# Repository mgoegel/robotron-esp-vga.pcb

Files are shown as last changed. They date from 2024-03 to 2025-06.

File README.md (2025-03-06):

# Robotron VGA Adapter PCB

This project is based on the work of Stefan "Ordoban" Berndt.

ESP32S3 based MDA to VGA adapter

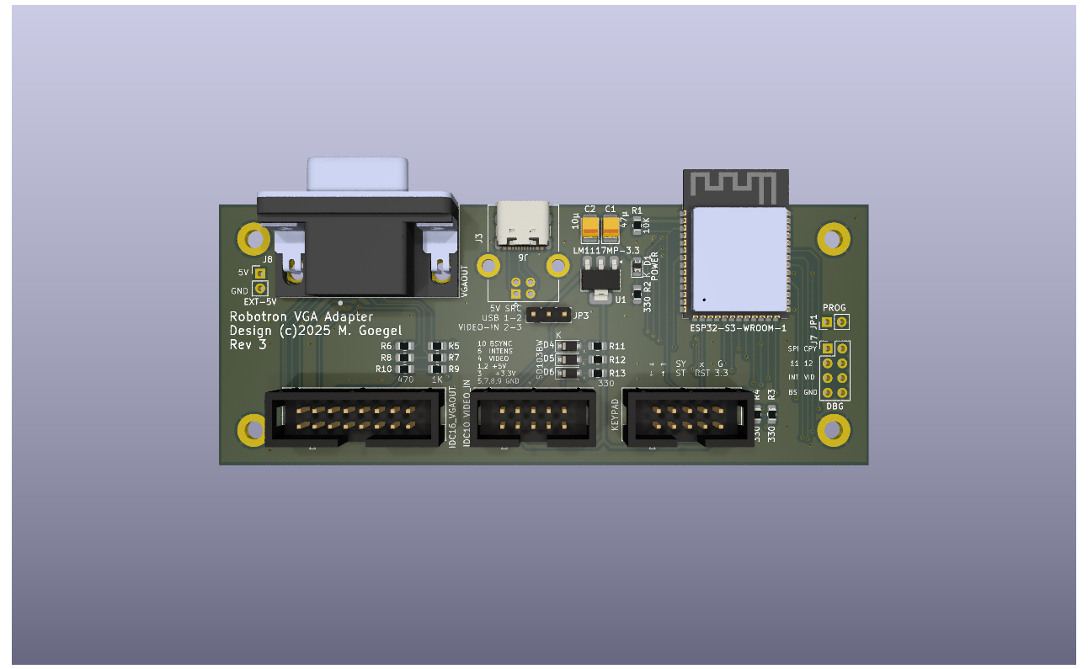
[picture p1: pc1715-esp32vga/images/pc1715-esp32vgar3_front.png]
VGA Adapter Front Adapter PCB Front
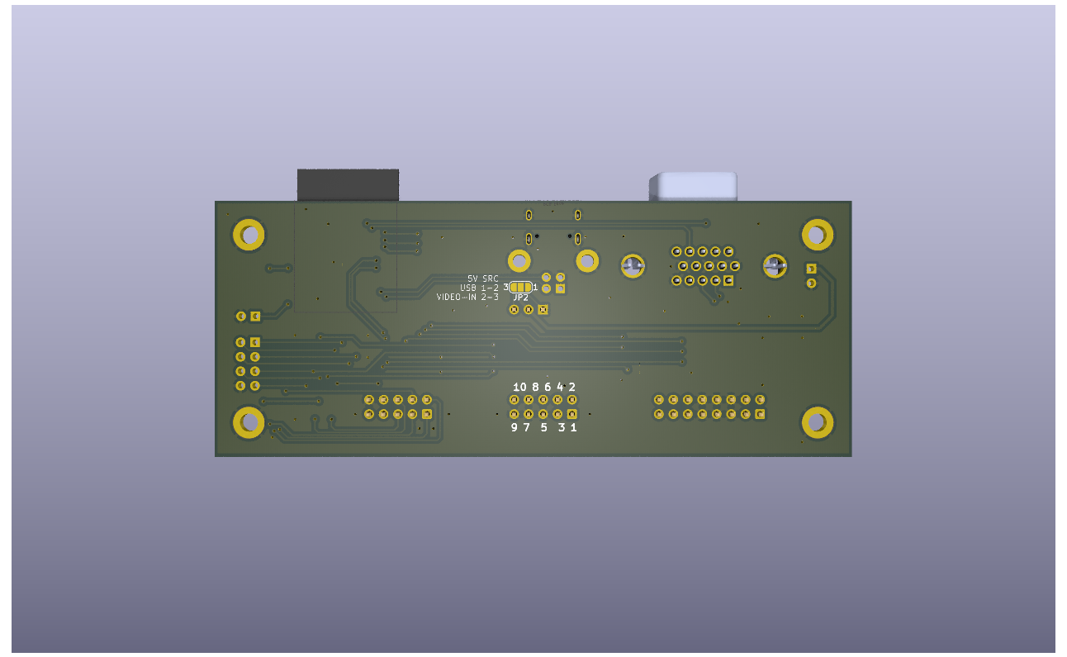
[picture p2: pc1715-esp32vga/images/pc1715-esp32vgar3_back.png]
VGA Adapter Back Adapter PCB Back
 

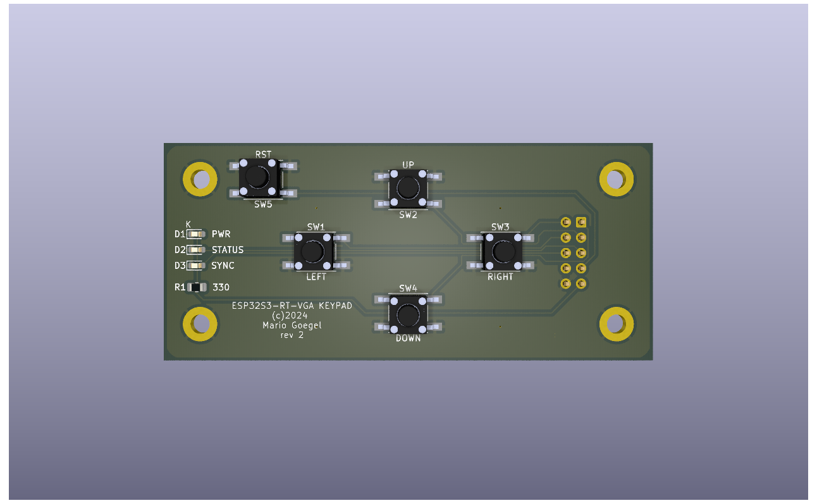
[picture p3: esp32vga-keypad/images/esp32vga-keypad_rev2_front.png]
Keypad Front
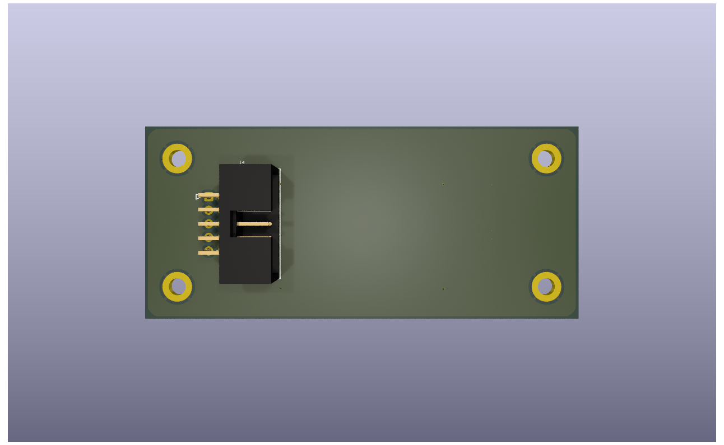
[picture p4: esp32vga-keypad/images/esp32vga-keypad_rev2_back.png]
Keypad Back
 

[Schematics](pc1715-esp32vga/schematics/pc1715-esp32vga.pdf)

Supported systems: <br>
[Connection A7100](Connections.md)
* A7100 
* A7150/CM1910 Text-only
* EC1834 MON Adapter (K7228.1, K7229.21-.24, Alpha 1 Monitor replacement)

[Connection PC1715](Connections.md)
* PC1715 
* A5120/K8924
* MC 80.30

[Connection VIDEO3/NANOS](Connections.md)
* NANOS

Published at: https://www.robotrontechnik.de/html/forum/thwb/showtopic.php?threadid=21380

The software is here: https://github.com/mgoegel/robotron-esp-vga

An (little bit outdated) order list is available at reichelt: https://www.reichelt.de/my/2181752<br>
I'll add mouser, as soon as I found out, how to publish the list... ;-)

Also you can find the BOM for both PCBs
* [Main board](pc1715-esp32vga/bom/ibom.html)
* [Keypad](esp32vga-keypad/bom/ibom.html)

### Main Board PIN Connector PINOUT

#### VGA J2 (D-SUB 15HD) / J5 (IDC16_VGA)

| D_SUB 15 HD | Signal | Pin | Pin | Signal | D_SUB 15 HD |
| --- | --- | --- | --- | --- | --- |
| 1 | RED | 1 | 2 | GREEN  | 2 |
| 3 | BLUE | 3 | 4 | NC | |
| 6 | GND | 5 | 6 | GND | 5 |
| 7 | GND | 7 | 8 | GND | 10 |
| 8 | GND | 9 | 10  | GND | NC |
| | NC | 11  | 12  | NC | |
| 13 | HSYNC  | 13  | 14  | VSYNC  | 14 |
| | NC | 15  | 16  | NC | |

#### VIDEO IN J1

| Signal | Pin | Pin | Signal |
| --- | --- | --- | --- |
| 5V IN | 1 | 2 | 5V IN  |
| 3.3V IN/OUT | 3 | 4 | VIDEO  |
| GND | 5 | 6 | INTENS |
| GND | 7 | 8 | GND |
| GND | 9 | 10  | BSYNC  |

#### KEYPAD J4

| Signal  | Pin | Pin | Signal  |
| --- | --- | --- | --- |
| K_DOWN  | 1 | 2 | K_RIGHT |
| K_UP | 3 | 4 | K_LEFT  |
| L_STAT  | 5 | 6 | L_SYNC  |
| RST | 7 | 8 | NC |
| 3.3V | 9 | 10  | GND |

#### DEBUG J7 2x04

| Signal | Pin | Pin | Signal |
| --- | --- | --- | --- |
| TP-SPI | 1 | 2 | TP-CPY |
| TP-11  | 3 | 4 | TP-12  |
| INTENS | 5 | 6 | VIDEO  |
| BSYNC  | 7 | 8 | GND |

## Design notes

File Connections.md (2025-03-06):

         ESP32S3VGA                                      PC1715            
          VIDEO-IN                                                         
                                                                           
                                                          A  B             
          ┌──────┐                                     ┌────────┐          
          │      │                                     │        │          
    BSYNC │ 0    ├───────────────────────────┐  ┌──────┤  1     │  INTENS  
       GND│    9 │                           │  │      │        │          
    GND   │ 8    ├───────────────────────────┼──┼──────┤     2  │  GND     
       GND│    7 │                      ┌────┼──┘      │        │          
    INTENS│ 6    ├──────────────────────┘    └─────────┤  3     │  BSYN    
       GND│    5 │                                     │        │          
    VIDEO │ 4    ├──────────────────────┐              │     4  │  SHIELD  
       3V3│    3 │                      │              │        │          
    5V    │ 2    │                      └──────────────┤  5     │  VIDEO   
        5V│    1 │                                     │        │          
          │      │<                                    └────────┘          
          └──────┘                                                         

         ESP32S3VGA                                     EC1834MON          
          VIDEO-IN                                        ALPHA1           
                                                                           
          ┌──────┐                                                         
          │      │                                     ┌─────────┐         
    BSYNC │ 0    ├────────┐                            │         │         
       GND│    9 │        │                            │     5   │         
    GND   │ 8    ├────┐   │   ┌────────────────────────┤  6      │  INTENS 
       GND│    7 │    │   │   │                        │     4   │       NC
    INTENS│ 6    ├────┼───┼───┘  ┌─────────────────────┤  7      │  VIDEO  
       GND│    5 │    │   │      │                     │     3   │       NC
    VIDEO │ 4    ├────┼───┼──────┘                     │  8      │  NC     
       3V3│    3 │    └───┼────────────────────────────┤     2   │      GND
    5V    │ 2    │        └────────────────────────────┤  9      │  BSYN   
        5V│    1 │                                     │     1   │      GND
          │      │<                                    │         │         
          └──────┘                                     └─────────┘         

        ESP32S3VGA                                       VIDEO3          
          VIDEO-IN                                        NANOS          
                                                                         
                                                          A  B           
          ┌──────┐                                     ┌────────┐        
          │      │                                     │        │        
    BSYNC │ 0    ├───────────────────────────┐         │  1     │  (BAS) 
       GND│    9 │                           │         │        │        
    GND   │ 8    ├───────────────────────────┼─────────┤     2  │  GND   
       GND│    7 │                           │         │        │        
    INTENS│ 6    │                           └─────────┤  3     │  BSYN  
       GND│    5 │                                     │        │        
    VIDEO │ 4    ├──────────────────────┐              │     4  │  SHIELD
       3V3│    3 │                      │              │        │        
    5V    │ 2    │                      └──────────────┤  5     │  VIDEO 
        5V│    1 │                                     │        │        
          │      │<                                    └────────┘        
          └──────┘

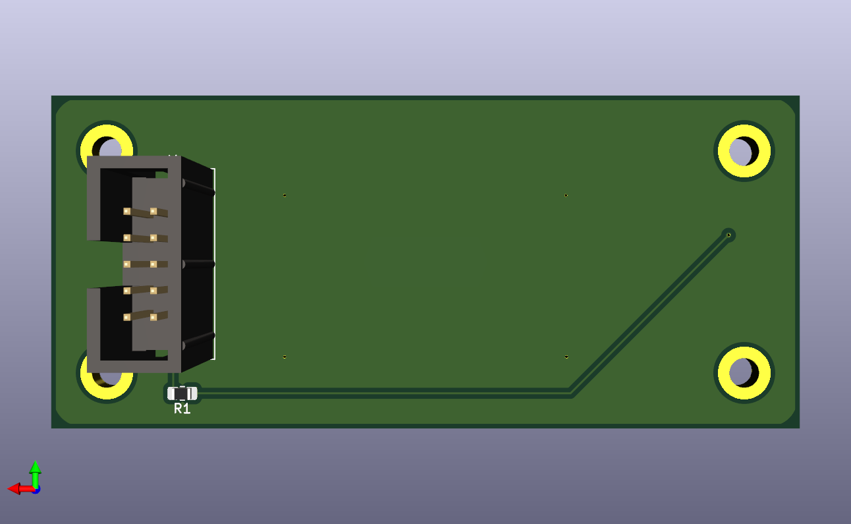
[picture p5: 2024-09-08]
esp32vga-keypad/images/esp32vga-keypad_back.png

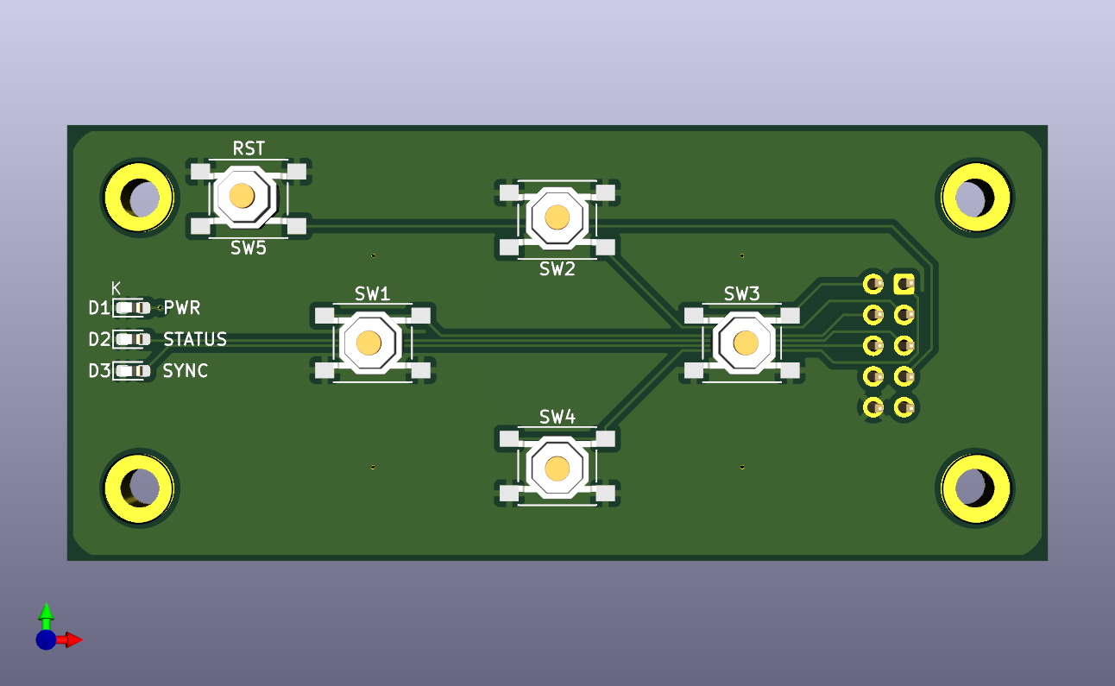
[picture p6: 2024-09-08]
esp32vga-keypad/images/esp32vga-keypad_front.png

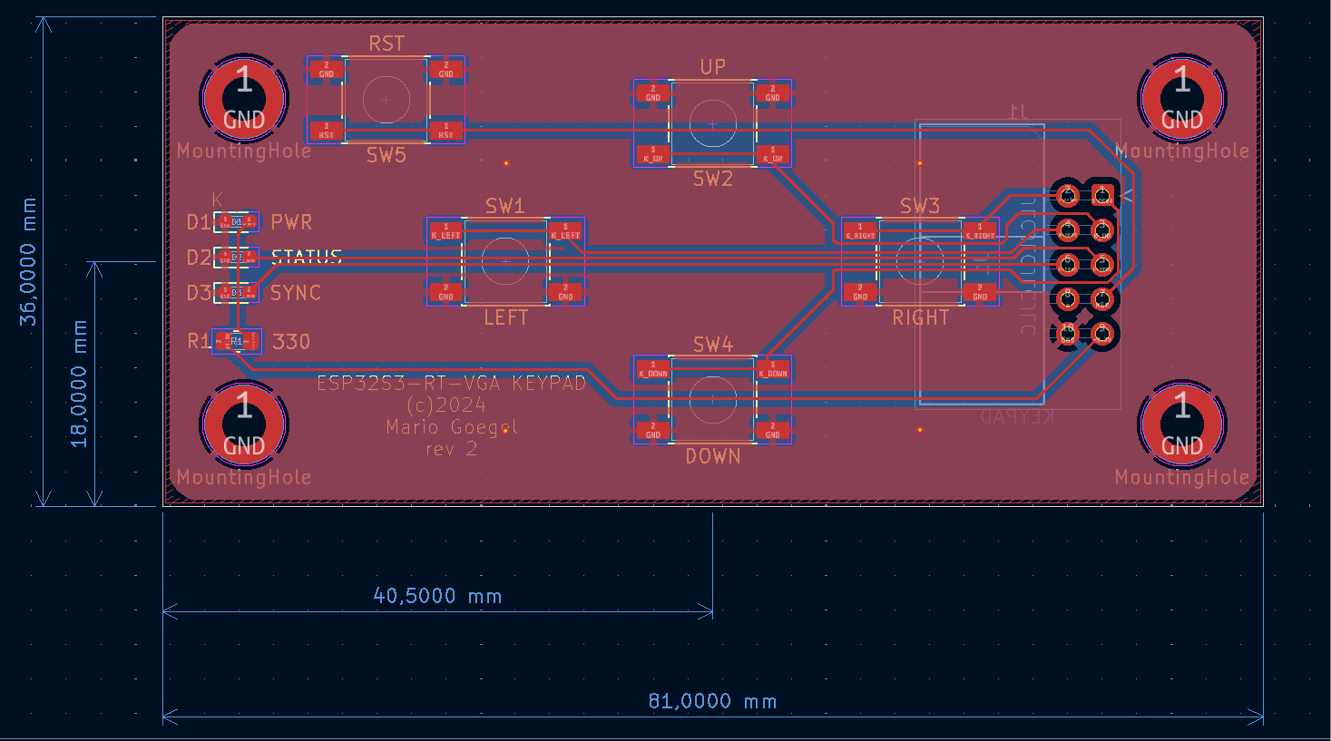
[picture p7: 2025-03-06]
esp32vga-keypad/images/esp32vga-keypad_rev2_pcb.png

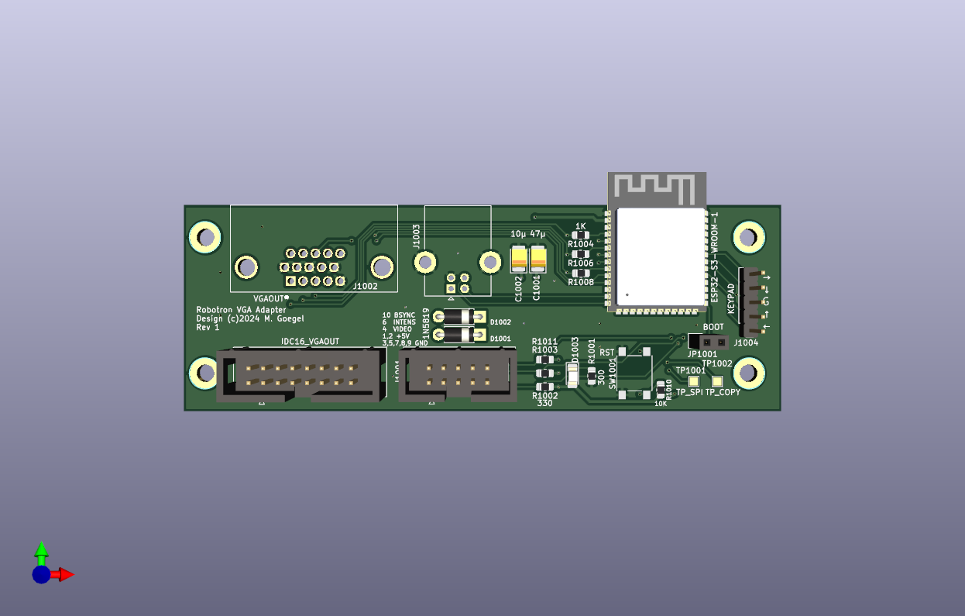
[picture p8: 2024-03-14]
pc1715-esp32vga/images/pc1715-esp32vga_front.png

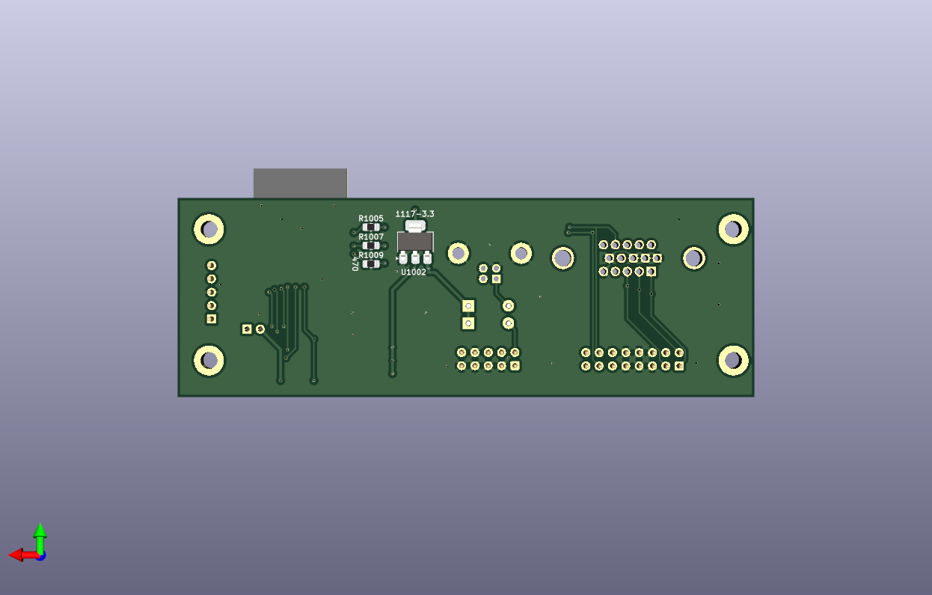
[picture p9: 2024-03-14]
pc1715-esp32vga/images/pc1715-esp32vga_back.png

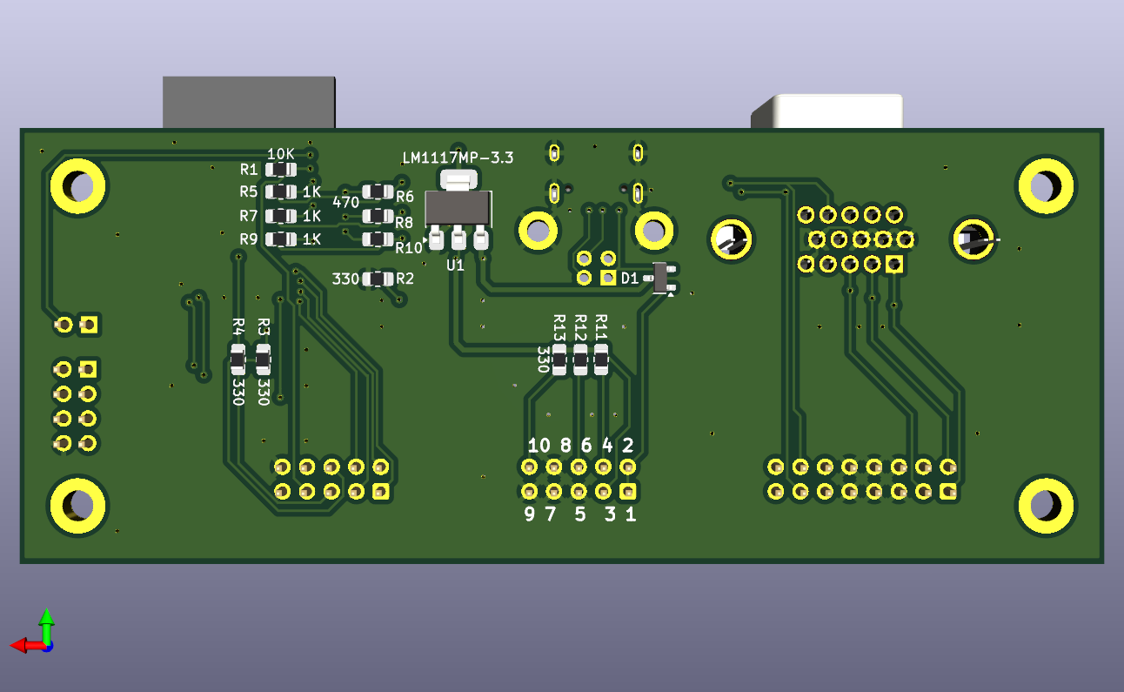
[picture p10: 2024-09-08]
pc1715-esp32vga/images/pc1715-esp32vgar2_back.png

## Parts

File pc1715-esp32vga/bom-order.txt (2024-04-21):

Reference	Value	Footprint	Qty	mouser	reichelt
C1001	47µ	Capacitor_Tantalum_SMD:CP_EIA-3528-21_Kemet-B_Pad1.50x2.35mm_HandSolder	1	581-TAJB476M010SNJ	TPS 3225 47/10
C1002	10µ	Capacitor_Tantalum_SMD:CP_EIA-3528-21_Kemet-B_Pad1.50x2.35mm_HandSolder	1	80-T491B106M020	TAJ 3528 10/20
D1001,D1002	1N5819	Diode_THT:D_DO-41_SOD81_P7.62mm_Horizontal	2	637-1N5819	1N 5819
D1003	LED	LED_SMD:LED_1206_3216Metric_Pad1.42x1.75mm_HandSolder	1	645-597-5411-407NF	SMD-LED 0805 GE
J1001	IDC10_VIDEO_IN	Connector_IDC:IDC-Header_2x05_P2.54mm_Vertical	1	710-61201021621	WSL 10G
J1002	VGAOUT	00esp32vga-footprints:TE_1-1734530-1	1	HD 15FW	571-2311763-1
J1003	USB_B	Connector_USB:USB_B_Lumberg_2411_02_Horizontal	1	USB BW	179-UJ2-B-HR-G-TH
J1004	KEYPAD	Connector_PinHeader_2.54mm:PinHeader_1x05_P2.54mm_Vertical	1		
J1005	IDC16_VGAOUT	Connector_IDC:IDC-Header_2x08_P2.54mm_Vertical	1	710-61201621621	WSL 16G
JP1001	BOOT	Connector_PinSocket_2.54mm:PinSocket_1x02_P2.54mm_Vertical	1		
R1001	300	Resistor_SMD:R_0805_2012Metric_Pad1.20x1.40mm_HandSolder	1		
R1002,R1003,R1011	330	Resistor_SMD:R_0805_2012Metric_Pad1.20x1.40mm_HandSolder	3		
R1004,R1006,R1008	1K	Resistor_SMD:R_0805_2012Metric_Pad1.20x1.40mm_HandSolder	3		
R1005,R1007,R1009	470	Resistor_SMD:R_0805_2012Metric_Pad1.20x1.40mm_HandSolder	3		
R1010	10K	Resistor_SMD:R_0805_2012Metric_Pad1.20x1.40mm_HandSolder	1		
SW1001	RST	Button_Switch_SMD:SW_Push_1P1T_NO_6x6mm_H9.5mm	1	653-B3FS-1002P	TASTER 9313
U1001	ESP32-S3-WROOM-1	PCM_Espressif:ESP32-S3-WROOM-1	1	356-ESP32S3WRM1UN8R8	ESP32S3WRM1N8R8
U1002	LM1117MP-3.3	Package_TO_SOT_SMD:SOT-223-3_TabPin2	1	926-LM1117MPX3.3NOPB	LM 1117 MPX-3.3

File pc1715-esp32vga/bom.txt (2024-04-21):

Reference	Value	Footprint	Qty	DNP
C1001	47µ	Capacitor_Tantalum_SMD:CP_EIA-3528-21_Kemet-B_Pad1.50x2.35mm_HandSolder	1	
C1002	10µ	Capacitor_Tantalum_SMD:CP_EIA-3528-21_Kemet-B_Pad1.50x2.35mm_HandSolder	1	
D1001,D1002	1N5819	Diode_THT:D_DO-41_SOD81_P7.62mm_Horizontal	2	
D1003	LED	LED_SMD:LED_1206_3216Metric_Pad1.42x1.75mm_HandSolder	1	
H1001,H1002,H1003,H1004	MountingHole	MountingHole:MountingHole_3.2mm_M3_ISO7380_Pad	4	
J1001	IDC10_VIDEO_IN	Connector_IDC:IDC-Header_2x05_P2.54mm_Vertical	1	
J1002	VGAOUT	00esp32vga-footprints:TE_1-1734530-1	1	
J1003	USB_B	Connector_USB:USB_B_Lumberg_2411_02_Horizontal	1	
J1004	KEYPAD	Connector_PinHeader_2.54mm:PinHeader_1x05_P2.54mm_Vertical	1	
J1005	IDC16_VGAOUT	Connector_IDC:IDC-Header_2x08_P2.54mm_Vertical	1	
JP1001	BOOT	Connector_PinSocket_2.54mm:PinSocket_1x02_P2.54mm_Vertical	1	
R1001	300	Resistor_SMD:R_0805_2012Metric_Pad1.20x1.40mm_HandSolder	1	
R1002,R1003,R1011	330	Resistor_SMD:R_0805_2012Metric_Pad1.20x1.40mm_HandSolder	3	
R1004,R1006,R1008	1K	Resistor_SMD:R_0805_2012Metric_Pad1.20x1.40mm_HandSolder	3	
R1005,R1007,R1009	470	Resistor_SMD:R_0805_2012Metric_Pad1.20x1.40mm_HandSolder	3	
R1010	10K	Resistor_SMD:R_0805_2012Metric_Pad1.20x1.40mm_HandSolder	1	
SW1001	RST	Button_Switch_SMD:SW_Push_1P1T_NO_6x6mm_H9.5mm	1	
TP1001	TP_SPI	TestPoint:TestPoint_Pad_1.5x1.5mm	1	
TP1002	TP_COPY	TestPoint:TestPoint_Pad_1.5x1.5mm	1	
U1001	ESP32-S3-WROOM-1	PCM_Espressif:ESP32-S3-WROOM-1	1	
U1002	LM1117MP-3.3	Package_TO_SOT_SMD:SOT-223-3_TabPin2	1

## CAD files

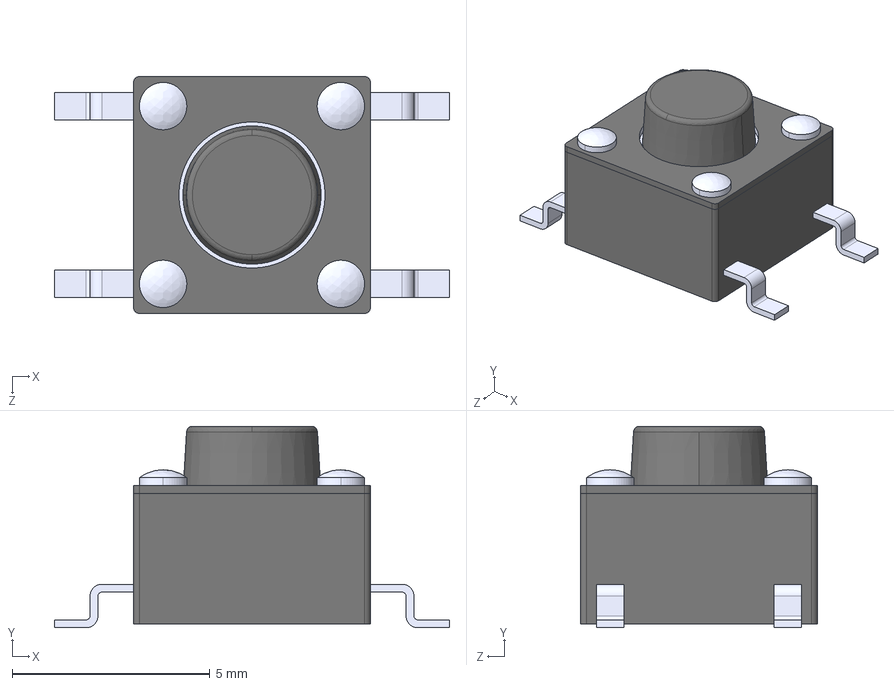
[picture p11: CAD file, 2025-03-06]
esp32vga-keypad/3d/TS04-66-50-BK-160-SMT.stp
10.0 x 5.10 x 6.00 mm

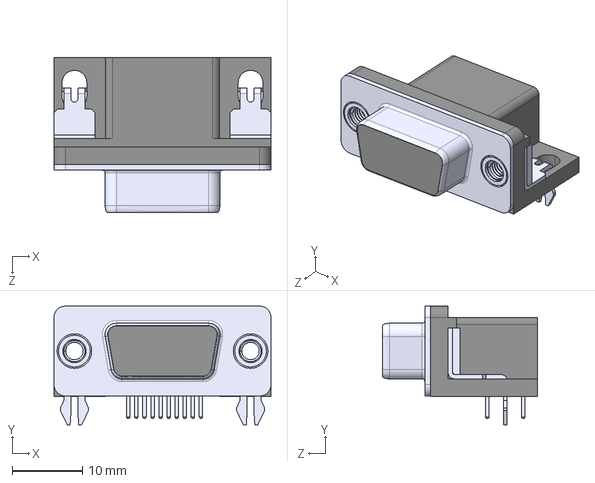
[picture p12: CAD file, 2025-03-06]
pc1715-esp32vga/3d/1-1734530-1.--3DModel-STEP-56544.STEP
30.8 x 16.9 x 22.0 mm

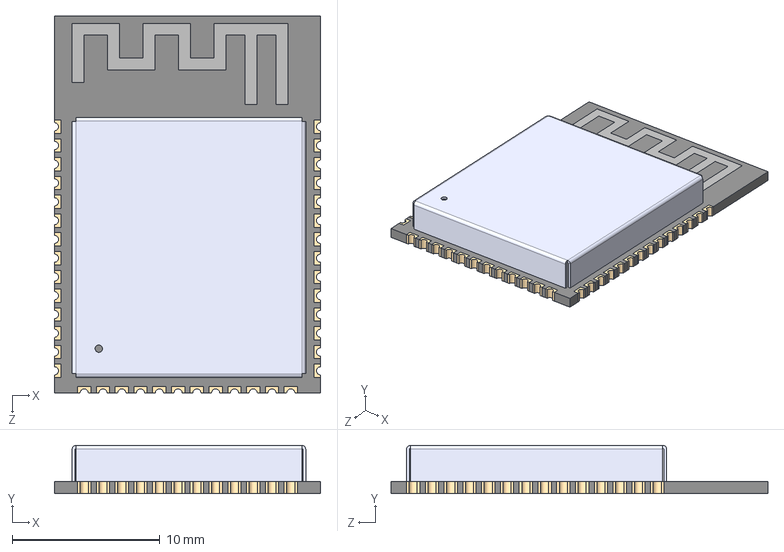
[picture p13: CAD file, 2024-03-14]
pc1715-esp32vga/3d/ESP32S3WROOM1N16R2.STEP
18.0 x 3.25 x 25.5 mm

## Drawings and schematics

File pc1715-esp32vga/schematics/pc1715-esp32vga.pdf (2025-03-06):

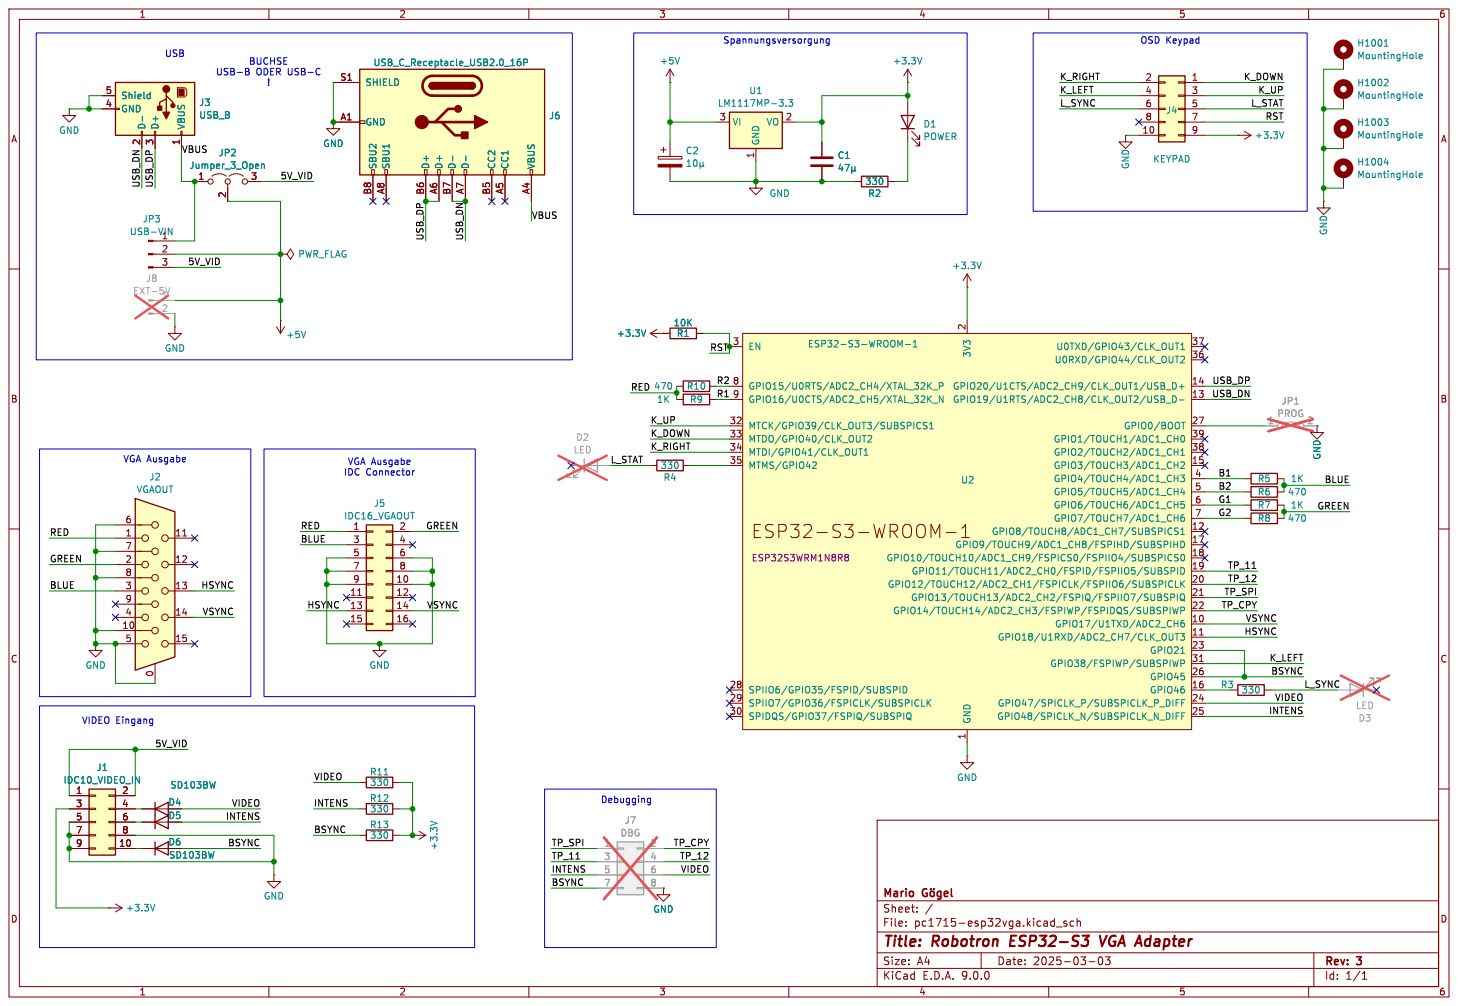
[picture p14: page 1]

1 U0TXD/GPIO43/CLK_OUT1 37 U0RXD/GPIO44/CLK_OUT2 36 GPIO20/U1CTS/ADC2_CH9/CLK_OUT1/USB_D+ 14 GPIO19/U1RTS/ADC2_CH8/CLK_OUT2/USB_D- 13 GPIO0/BOOT 27 GPIO1/TOUCH1/ADC1_CH0 39 GPIO2/TOUCH2/ADC1_CH1 38 GPIO3/TOUCH3/ADC1_CH2 15 GPIO4/TOUCH4/ADC1_CH3 4 GPIO5/TOUCH5/ADC1_CH4 5 GPIO6/TOUCH6/ADC1_CH5 6 GPIO7/TOUCH7/ADC1_CH6 7 GPIO8/TOUCH8/ADC1_CH7/SUBSPICS1 12 GPIO9/TOUCH9/ADC1_CH8/FSPIHD/SUBSPIHD 17 GPIO10/TOUCH10/ADC1_CH9/FSPICS0/FSPIIO4/SUBSPICS0 18 GPIO11/TOUCH11/ADC2_CH0/FSPID/FSPIIO5/SUBSPID 19 GPIO12/TOUCH12/ADC2_CH1/FSPICLK/FSPIIO6/SUBSPICLK 20 GPIO13/TOUCH13/ADC2_CH2/FSPIQ/FSPIIO7/SUBSPIQ 21 GPIO14/TOUCH14/ADC2_CH3/FSPIWP/FSPIDQS/SUBSPIWP 22 GPIO17/U1TXD/ADC2_CH6 10 GPIO18/U1RXD/ADC2_CH7/CLK_OUT3 11 GPIO21 23 GPIO38/FSPIWP/SUBSPIWP 31 GPIO45 26 GPIO46 16 GPIO47/SPICLK_P/SUBSPICLK_P_DIFF 24 GPIO48/SPICLK_N/SUBSPICLK_N_DIFF 25 U2 ESP32-S3-WROOM-1 ESP32S3WRM1N8R8

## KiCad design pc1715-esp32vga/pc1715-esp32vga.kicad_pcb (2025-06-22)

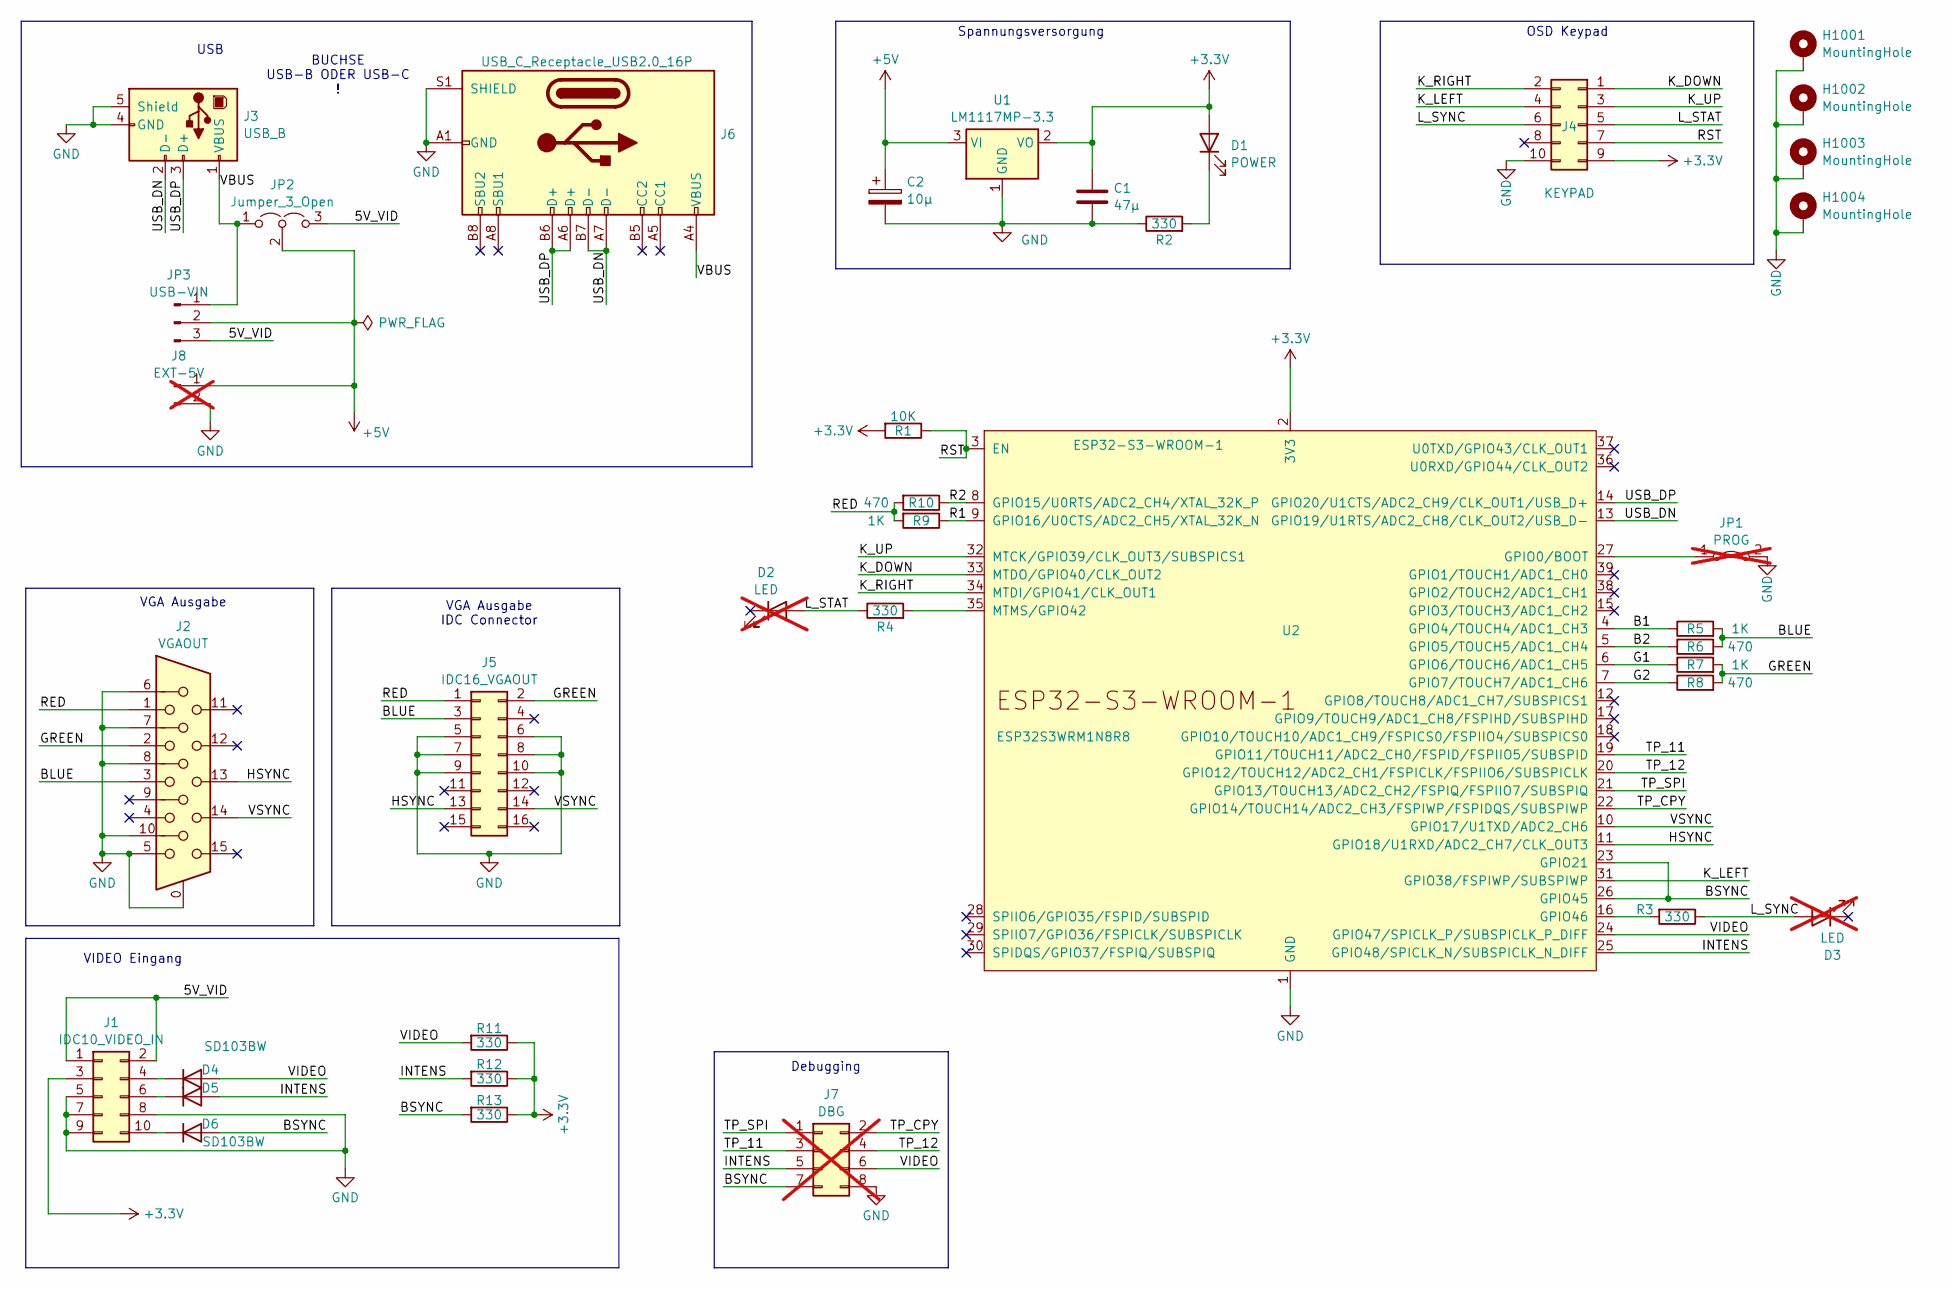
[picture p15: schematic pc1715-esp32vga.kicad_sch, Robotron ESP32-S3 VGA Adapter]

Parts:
C1: 47µ; CP_EIA-3528-21_Kemet-B_Pad1.50x2.35mm_HandSolder
C2: 10µ; CP_EIA-3528-21_Kemet-B_Pad1.50x2.35mm_HandSolder
D1: POWER; D_0805_2012Metric_Pad1.15x1.40mm_HandSolder
D2, D3: LED; not fitted
D4, D5, D6: SD103BW; D_SOD-123
H1001, H1002, H1003, H1004: MountingHole; MountingHole_3.2mm_M3_ISO7380_Pad
J1: IDC10_VIDEO_IN; IDC-Header_2x05_P2.54mm_Vertical
J2: VGAOUT; TE_1-1734530-1
J3: USB_B; USB_B_Lumberg_2411_02_Horizontal
J4: KEYPAD; IDC-Header_2x05_P2.54mm_Vertical
J5: IDC16_VGAOUT; IDC-Header_2x08_P2.54mm_Vertical
J6: USB_C_Receptacle_USB2.0_16P; USB_C_Receptacle_GCT_USB4105-xx-A_16P_TopMnt_Horizontal
J7: DBG; PinHeader_2x04_P2.54mm_Vertical; not fitted
J8: EXT-5V; PinHeader_1x02_P2.54mm_Vertical; not fitted
JP1: PROG; PinHeader_1x02_P2.54mm_Vertical; not fitted
JP2: Jumper_3_Open; SolderJumper-3_P1.3mm_Open_RoundedPad1.0x1.5mm_NumberLabels
JP3: USB-VIN; PinHeader_1x03_P2.54mm_Vertical
R1: 10K; R_0805_2012Metric_Pad1.20x1.40mm_HandSolder
R2, R3, R4, R11, R12, R13: 330; R_0805_2012Metric_Pad1.20x1.40mm_HandSolder
R5, R7, R9: 1K; R_0805_2012Metric_Pad1.20x1.40mm_HandSolder
R6, R8, R10: 470; R_0805_2012Metric_Pad1.20x1.40mm_HandSolder
U1: LM1117MP-3.3; SOT-223-3_TabPin2
U2: ESP32-S3-WROOM-1

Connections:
+3.3V: C1.1, D1.2 (A), J1.3, J4.9, R1.2, R11.1, R12.1, R13.1, U1.2 (VO), U2.2 (3V3)
+5V: C2.1, J8.1, JP2.2 (C), JP3.2, U1.3 (VI)
/5V_VID: J1.1, J1.2, JP2.3 (B), JP3.3
/B1: R5.1, U2.4 (GPIO4/TOUCH4/ADC1_CH3)
/B2: R6.1, U2.5 (GPIO5/TOUCH5/ADC1_CH4)
/BLUE: J2.3, J5.3, R5.2, R6.2
/BSYNC: D6.2 (A), J7.7, R13.2, U2.23 (GPIO21), U2.26 (GPIO45)
/G1: R7.1, U2.6 (GPIO6/TOUCH6/ADC1_CH5)
/G2: R8.1, U2.7 (GPIO7/TOUCH7/ADC1_CH6)
/GREEN: J2.2, J5.2, R7.2, R8.2
/HSYNC: J2.13, J5.13, U2.11 (GPIO18/U1RXD/ADC2_CH7/CLK_OUT3)
/INTENS: D5.2 (A), J7.5, R12.2, U2.25 (GPIO48/SPICLK_N/SUBSPICLK_N_DIFF)
/K_DOWN: J4.1, U2.33 (MTDO/GPIO40/CLK_OUT2)
/K_LEFT: J4.4, U2.31 (GPIO38/FSPIWP/SUBSPIWP)
/K_RIGHT: J4.2, U2.34 (MTDI/GPIO41/CLK_OUT1)
/K_UP: J4.3, U2.32 (MTCK/GPIO39/CLK_OUT3/SUBSPICS1)
/L_STAT: D2.2 (A), J4.5, R4.1
/L_SYNC: D3.2 (A), J4.6, R3.1
/R1: R9.1, U2.9 (GPIO16/U0CTS/ADC2_CH5/XTAL_32K_N)
/R2: R10.1, U2.8 (GPIO15/U0RTS/ADC2_CH4/XTAL_32K_P)
/RED: J2.1, J5.1, R9.2, R10.2
/RST: J4.7, R1.1, U2.3 (EN)
/TP_11: J7.3, U2.19 (GPIO11/TOUCH11/ADC2_CH0/FSPID/FSPIIO5/S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)
/TP_12: J7.4, U2.20 (GPIO12/TOUCH12/ADC2_CH1/FSPICLK/FSPIIO6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)
/TP_CPY: J7.2, U2.22 (GPIO14/TOUCH14/ADC2_CH3/FSPIWP/FSPIDQS/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)
/TP_SPI: J7.1, U2.21 (GPIO13/TOUCH13/ADC2_CH2/FSPIQ/FSPIIO7/S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)
/USB_DN: J3.2 (D-), J6.A7 (D-), J6.B7 (D-), U2.13 (GPIO19/U1RTS/ADC2_CH8/CLK_OUT2/USB_D-)
/USB_DP: J3.3 (D+), J6.A6 (D+), J6.B6 (D+), U2.14 (GPIO20/U1CTS/ADC2_CH9/CLK_OUT1/USB_D+)
/VBUS: J3.1 (VBUS), J6.A4 (VBUS), J6.A9 (VBUS), J6.B4 (VBUS), J6.B9 (VBUS), JP2.1 (A), JP3.1
/VIDEO: D4.2 (A), J7.6, R11.2, U2.24 (GPIO47/SPICLK_P/SUBSPICLK_P_DIFF)
/VSYNC: J2.14, J5.14, U2.10 (GPIO17/U1TXD/ADC2_CH6)
GND: C1.2, C2.2, H1001.1, H1002.1, H1003.1, H1004.1, J1.5, J1.7, J1.8, J1.9, J2.0, J2.5, J2.6, J2.7, J2.8, J2.10, J3.4 (GND), J3.5 (Shield), J4.10, J5.5, J5.6, J5.7, J5.8, J5.9, J5.10, J6.A1 (GND), J6.A12 (GND), J6.B1 (GND), J6.B12 (GND), J6.S1 (SHIELD), J7.8, J8.2, JP1.2 (B), R2.1, U1.1 (GND), U2.1 (GND), U2.40 (GND), U2.41 (GND)
unnamed: D1.1 (K), R2.2
unnamed: D4.1 (K), J1.4
unnamed: D5.1 (K), J1.6
unnamed: D6.1 (K), J1.10
unnamed: JP1.1 (A), U2.27 (GPIO0/BOOT)
unnamed: R3.2, U2.16 (GPIO46)
unnamed: R4.2, U2.35 (MTMS/GPIO42)

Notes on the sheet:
VGA Ausgabe IDC Connector
Debugging
Spannungsversorgung
VIDEO Eingang
OSD Keypad
VGA Ausgabe
BUCHSE USB-B ODER USB-C !
USB

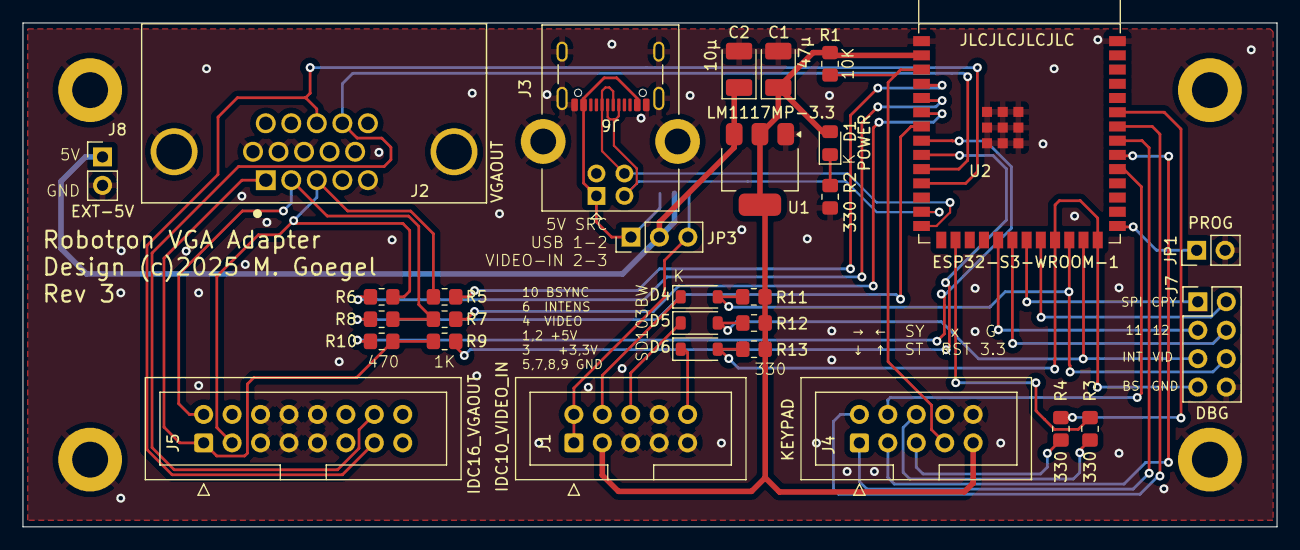
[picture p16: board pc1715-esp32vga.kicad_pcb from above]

Board: 2 copper layers, 112.0 x 45.0 mm, 36 parts (1 on the bottom side), 39 nets.

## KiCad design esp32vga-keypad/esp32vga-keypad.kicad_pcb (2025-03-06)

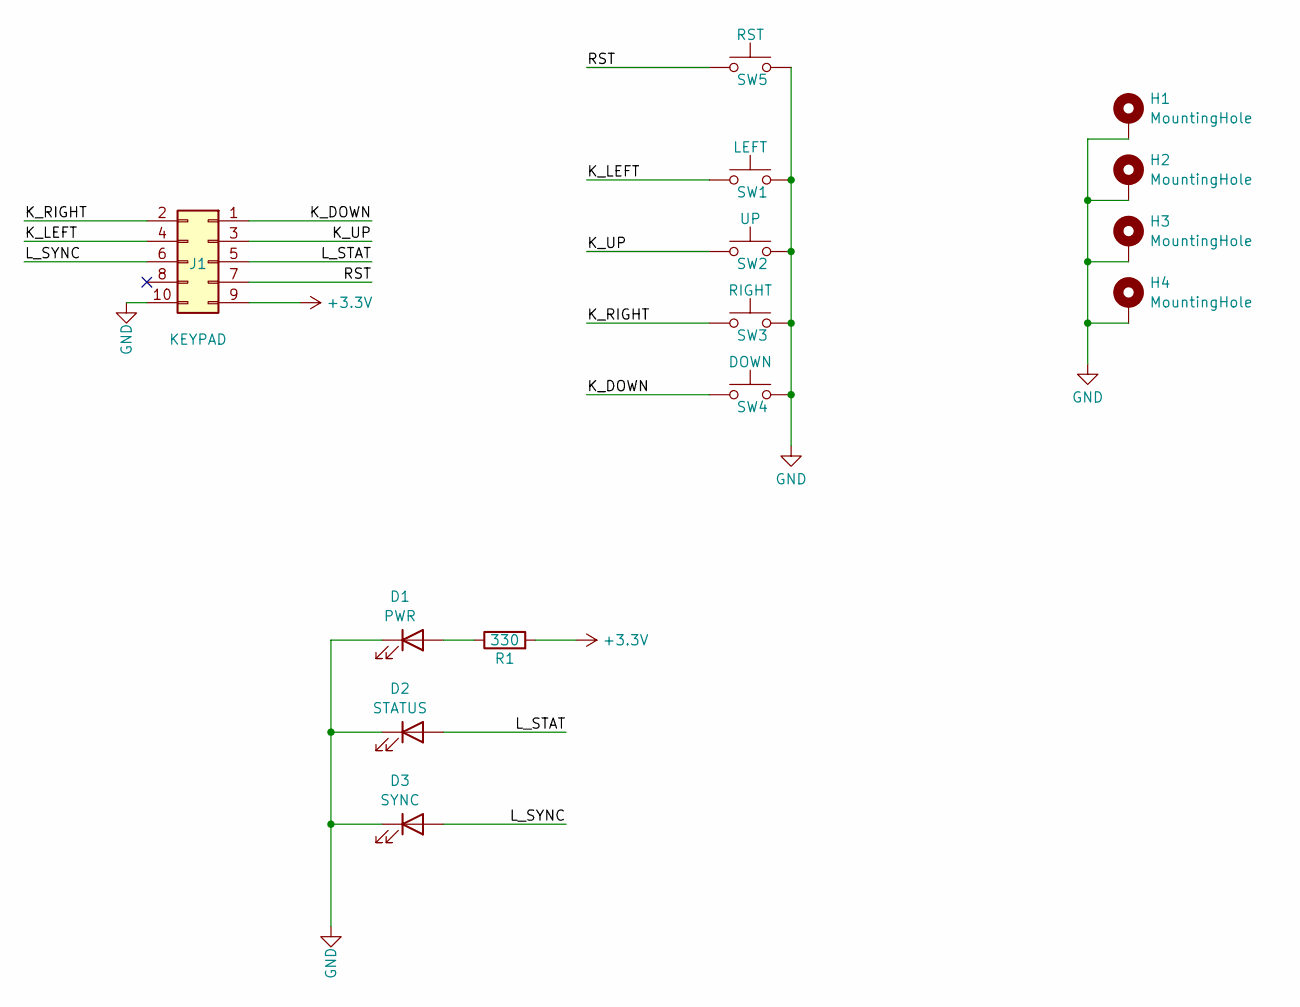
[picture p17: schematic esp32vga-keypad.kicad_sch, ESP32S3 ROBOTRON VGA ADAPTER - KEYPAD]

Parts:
D1: PWR; LED_0603_1608Metric_Pad1.05x0.95mm_HandSolder
D2: STATUS; LED_0603_1608Metric_Pad1.05x0.95mm_HandSolder
D3: SYNC; LED_0603_1608Metric_Pad1.05x0.95mm_HandSolder
H1, H2, H3, H4: MountingHole; MountingHole_3.2mm_M3_ISO7380_Pad
J1: KEYPAD; IDC-Header_2x05_P2.54mm_Horizontal
R1: 330; R_0805_2012Metric_Pad1.20x1.40mm_HandSolder
SW1: LEFT; SW_Push_TS04_NO_6x6mm_H5.00_BKXXX_SMT
SW2: UP; SW_Push_TS04_NO_6x6mm_H5.00_BKXXX_SMT
SW3: RIGHT; SW_Push_TS04_NO_6x6mm_H5.00_BKXXX_SMT
SW4: DOWN; SW_Push_TS04_NO_6x6mm_H5.00_BKXXX_SMT
SW5: RST; SW_Push_TS04_NO_6x6mm_H5.00_BKXXX_SMT

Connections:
+3.3V: J1.9, R1.2
/K_DOWN: J1.1, SW4.1
/K_LEFT: J1.4, SW1.1
/K_RIGHT: J1.2, SW3.1
/K_UP: J1.3, SW2.1
/L_STAT: D2.2 (A), J1.5
/L_SYNC: D3.2 (A), J1.6
/RST: J1.7, SW5.1
GND: D1.1 (K), D2.1 (K), D3.1 (K), H1.1, H2.1, H3.1, H4.1, J1.10, SW1.2, SW2.2, SW3.2, SW4.2, SW5.2
unnamed: D1.2 (A), R1.1

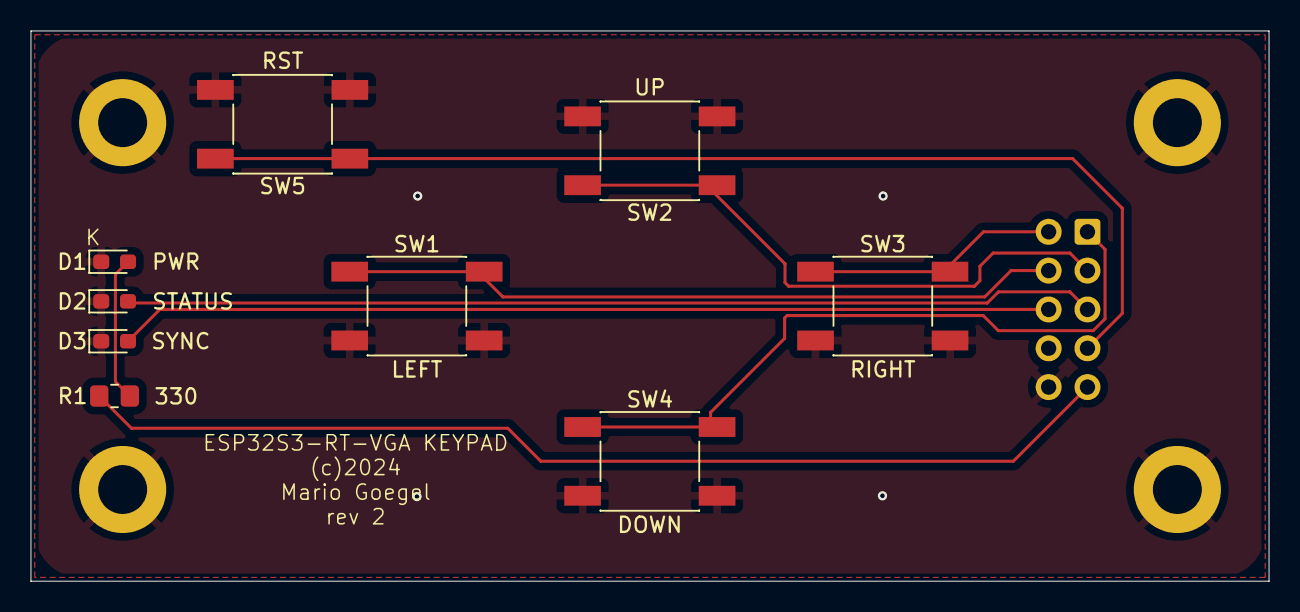
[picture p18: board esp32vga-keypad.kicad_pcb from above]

Board: 2 copper layers, 81.0 x 36.0 mm, 14 parts (1 on the bottom side), 10 nets.

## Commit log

2024-03-14 IDC10 Beschriftung
    [pc1715-esp32vga.kicad_pcb]
2024-04-21 Prototype #1 Gerber files added
    [pc1715-esp32vga-B_Cu.gbr, pc1715-esp32vga-B_Mask.gbr, pc1715-esp32vga-B_Paste.gbr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]
2024-08-04 Revision 2
    [pc1715-esp32vga-B_Cu.gbr, pc1715-esp32vga-B_Mask.gbr, pc1715-esp32vga-B_Paste.gbr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]
2024-09-07 Rev 2 Main PCB with keypad
    [esp32vga-keypad-B_Cu.gbr, esp32vga-keypad-B_Mask.gbr, esp32vga-keypad-B_Paste.gbr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]
2024-09-08 Documentation improved
    [pc1715-esp32vga-B_Cu.gbr, pc1715-esp32vga-B_Mask.gbr, pc1715-esp32vga-B_Paste.gbr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]
2024-12-15 Silkscreen correction for J4 Changed BOOT jumper to PROG jumper, Connection to GND instead VCC
    [pc1715-esp32vga-B_Cu.gbr, pc1715-esp32vga-B_Mask.gbr, pc1715-esp32vga-B_Paste.gbr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]
2025-03-06 Update to rev3
    [1-1734530-1.--3DModel-STEP-56544.STEP, TS04-66-50-BK-160-SMT.stp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]
2025-06-22 Added PCB comments Saved in Kicad 9
    [pc1715-esp32vga-B_Cu.gbr, pc1715-esp32vga-B_Mask.gbr, pc1715-esp32vga-B_Paste.gbr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]

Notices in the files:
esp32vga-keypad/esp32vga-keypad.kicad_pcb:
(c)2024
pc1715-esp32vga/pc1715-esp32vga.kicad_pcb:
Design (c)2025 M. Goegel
